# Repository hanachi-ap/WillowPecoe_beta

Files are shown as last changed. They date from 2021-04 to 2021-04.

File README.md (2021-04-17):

# WillowPecoe_beta

全国のWillowファンの皆様こんにちは。そしてβテストへようこそ。

## ビルドガイド(玄人向け)

MCUにProMicroを採用し、CherryMXスイッチ、PCB 3層サンドイッチと、ごくオーソドックスなスタイルを
採用しているので難しいところはないと思います。

基板がリバーシブルになっているので、パーツの取付面だけ注意ください。

## パーツリスト

- Pro Micro x1
- タクトスイッチ(2本足) x1
- MX用スイッチソケット x49
- ダイオード (TH or SMD) x50 
- フルカラーシリアルLED WS2812B x15 (opt)
- ロータリーエンコーダ x1  (opt)
  プッシュスイッチ対応。

  遊舎工房で販売している アメリカBourns社製 PEC12R-4222F-S0024 で動作を確認しています。
  その他秋月電子で販売しているロータリーエンコーダ（商品番号P-06357)もプシュスイッチ機能はありませんが動作確認済みです。

- 六角スペーサー(M2 7mm)  x13
- 六角スペーサー(M2 3.5mm) x6
- ネジ (M2 3mm) x38
- 2Uスタビライザ x1
- Cherry MX互換スイッチ x49
- キーキャップ (お好み)
  
## パーツの取付け
### 基板の表裏を決定
まず ロータリーエンコーダの位置を右か左か決めます。
 - 左側に置く場合、PCBのSide Aが表面になります。
 - 右側に置く場合、PCBのSide Bが表面になります。

### パーツのはんだ付け

#### ダイオード
- ダイオードは すべて裏面に取り付けます。 
  - SMD、TH どちらでも使えます。
  - 実際のところダイオードは表面につけても有効です。(見栄えの問題)
### スイッチソケット
- スイッチソケットはすべて裏面に取り付けます。

### RGB LED
- 表面側のパッドをジャンプさせます (Jump front sideと書いてあるところ)

- 表面に 3個、 裏面に12個取り付けます。
  - Side Aが表面の場合、 シルクのLED1からLED13に取り付けます。
  - Side Bが表面の場合、 シルクのLED16からLED30に取り付けます。

### ロータリーエンコーダ
- 表面からさして裏面をはんだ付けします。

### Pro Micro
 - ProMicroはコンスルーを使って表面に取り付けます。
 - ProMicroの実装面が内向きになるようにしてください。

### タクトスイッチ
  - 表面に取り付けます

## 組み立て

- トッププレートとPCBを3.5mmスペーサを使って取り付けます。
- スイッチを差し込みます。
- PCBと化粧板を7mmスペーサを使って取り付けます。
- トッププレートとボトムプレートを7mmスペーサを使って取り付けます。

## ファームウェア

- コンパイルしてください。ロリコンの位置によってキーマップが異なります。
  - Side A用: default
  - Side B用: side_b
  
## 既知の問題点

- アンダーグローの光がうまく廻りません。
  - アクリルプレートオプションを考慮します
  - 次の版では、簡単に表面の3つだけ優先的に光らせられるよう配線を見直します。
  - とりあえず表側の3個だけを光らすには 最初の5個だけを取り付けるか、ジャンパを這わせればOK。  

- PCBの表面に細かい油染みのような塗装ムラ?があります。
  - 製造委託先の品質に依存する問題かと思います。実質影響はありません。
  - 次の発注は別なところを考えてみます(量産のときはJLCPCBの価格は魅力なんだけど)
  
- ネジとスイッチが干渉する恐れがあるかも?
  - 作者手元のスイッチでは爪一枚入るくらいの余裕がありますが次の基板ではもう少し余裕持たせるようにします

- ファームウェアは開発途中です

- トッププレートのLEDを透過するスリットにはアクリルを埋め込む計画がありますが未実装です。
 
- 細かいキーレイアウトが作者の理想から少しだけ外れています。
  全体ををもう少し折り曲げたほうが好みなので修正が入るかもしれません

## 権利等
まだLICENSEを明記してませんが下記で公開する予定です。

- ファームウェア: GPL V2
- KiCAD設計データ: GPL V2
- KiCADフットプリント: MIT (thx foostan)
- 配列意匠: CC BY-SA 4.0 

以上です

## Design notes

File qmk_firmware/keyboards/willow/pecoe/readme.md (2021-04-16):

# pecoe

pecoe

*A short description of the keyboard/project*

* Keyboard Maintainer: [hanachi-ap](https://github.com/yourusername)
* Hardware Supported: *The PCBs, controllers supported*
* Hardware Availability: *Links to where you can find this hardware*

Make example for this keyboard (after setting up your build environment):

    make pecoe:default

Flashing example for this keyboard:

    make pecoe:default:flash

See the [build environment setup](https://docs.qmk.fm/#/getting_started_build_tools) and the [make instructions](https://docs.qmk.fm/#/getting_started_make_guide) for more information. Brand new to QMK? Start with our [Complete Newbs Guide](https://docs.qmk.fm/#/newbs).

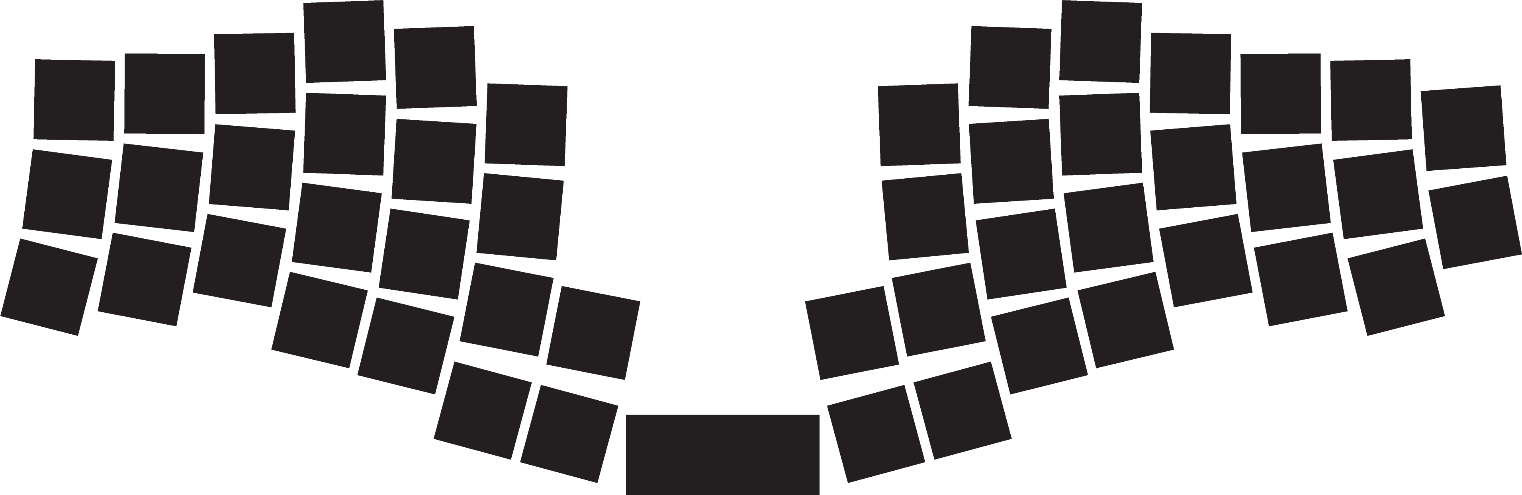
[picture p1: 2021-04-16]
pcb/kicad_lib/willow/png/F_switch_hole.png

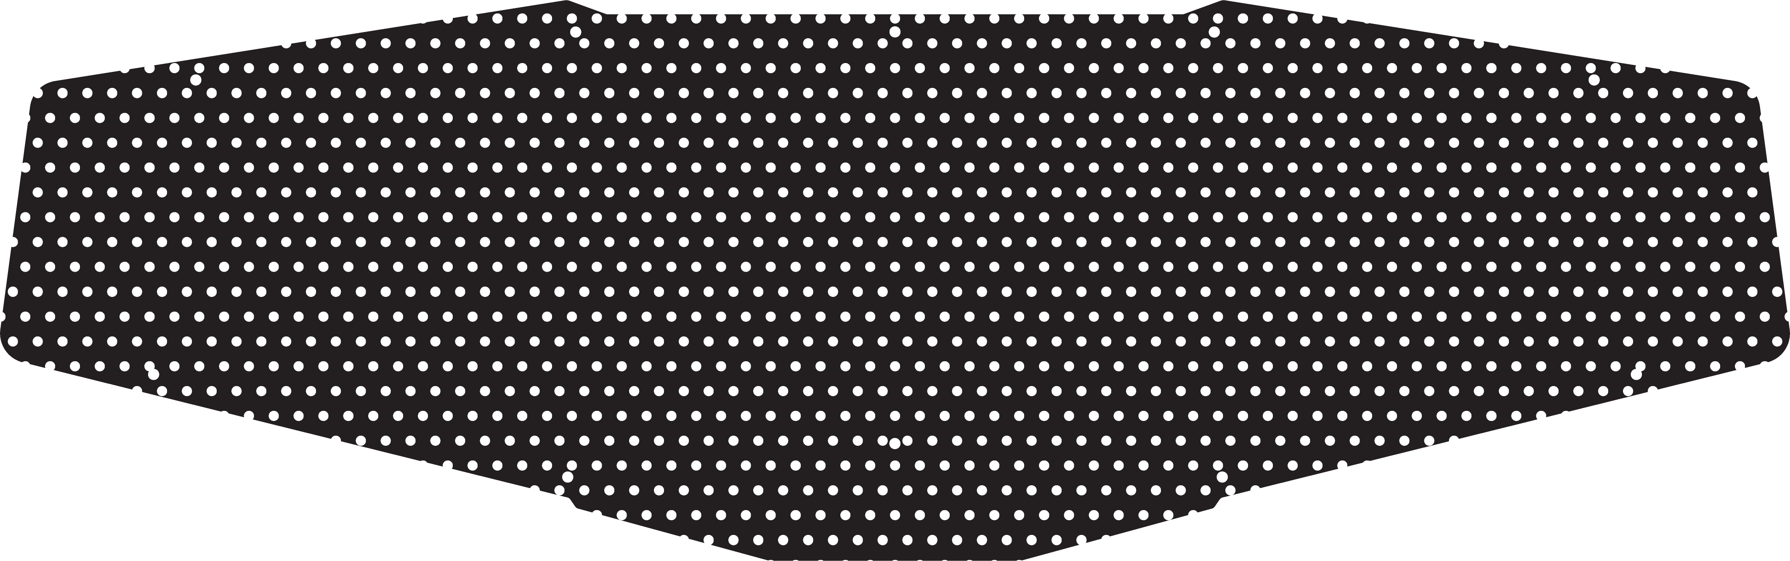
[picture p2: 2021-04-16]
pcb/WillowPecoe_bottom/bottom_pattern.png

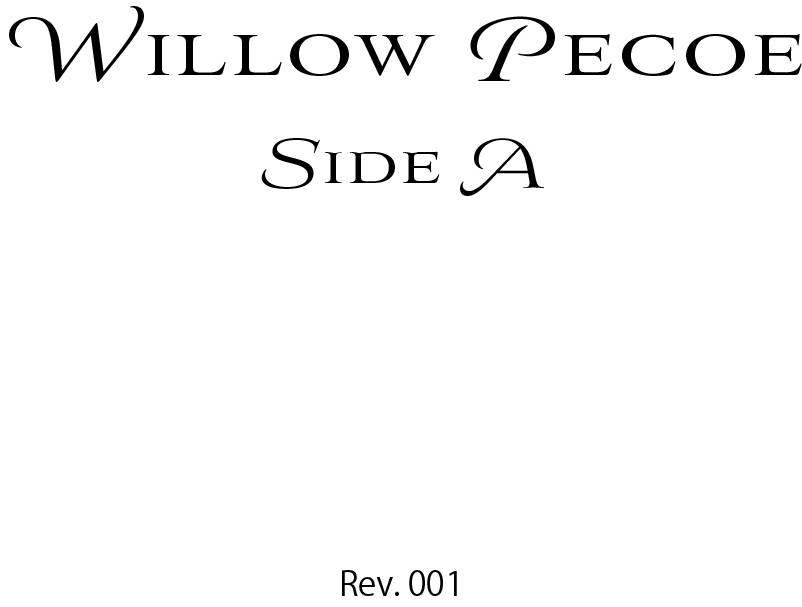
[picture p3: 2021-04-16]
pcb/WillowPecoe_pcb/Silk_F.png

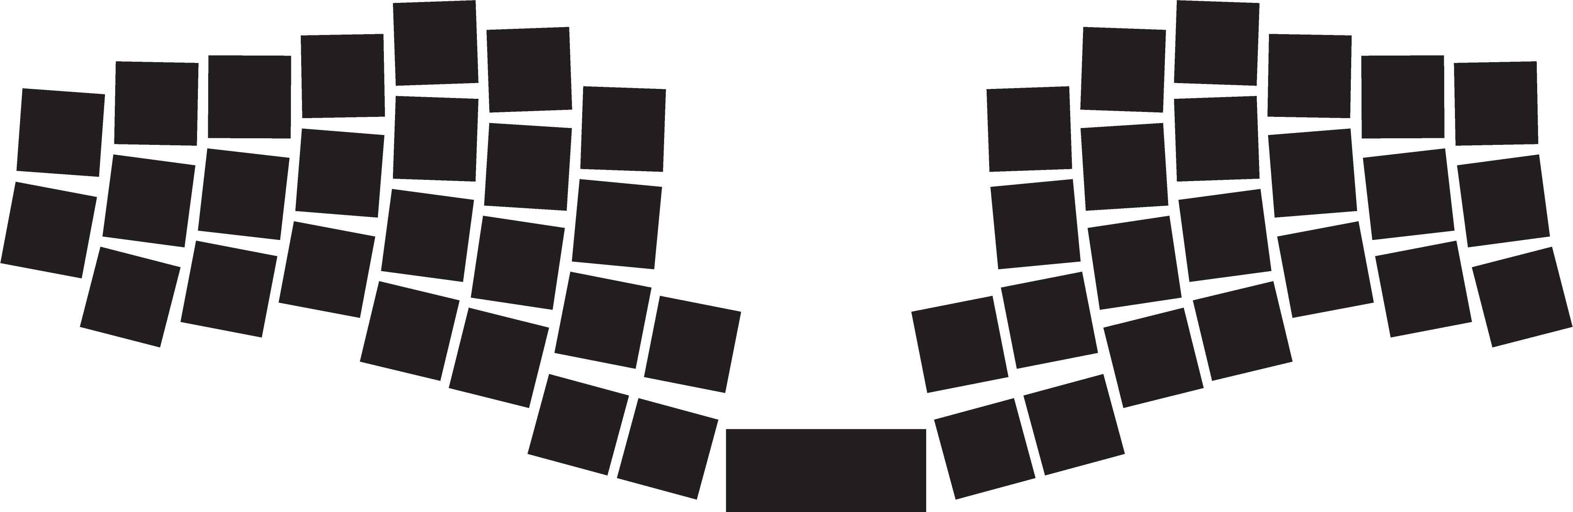
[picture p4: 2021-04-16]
pcb/kicad_lib/willow/png/B_switch_hole.png

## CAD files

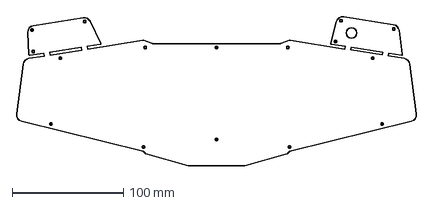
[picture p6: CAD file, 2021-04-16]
pcb/WillowPecoe_bottom/bottom_edge.dxf
360.8 x 134.4 mm

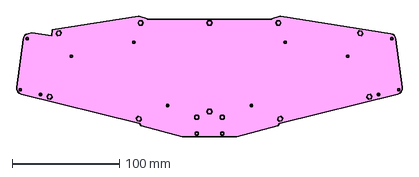
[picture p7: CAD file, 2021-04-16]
pcb/WillowPecoe_pcb/edge.dxf
360.8 x 112.8 mm

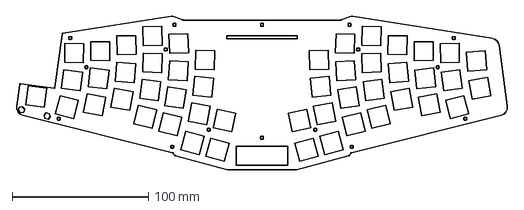
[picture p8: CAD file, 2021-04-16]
pcb/WillowPecoe_plate/edge_top.dxf
360.8 x 112.8 mm

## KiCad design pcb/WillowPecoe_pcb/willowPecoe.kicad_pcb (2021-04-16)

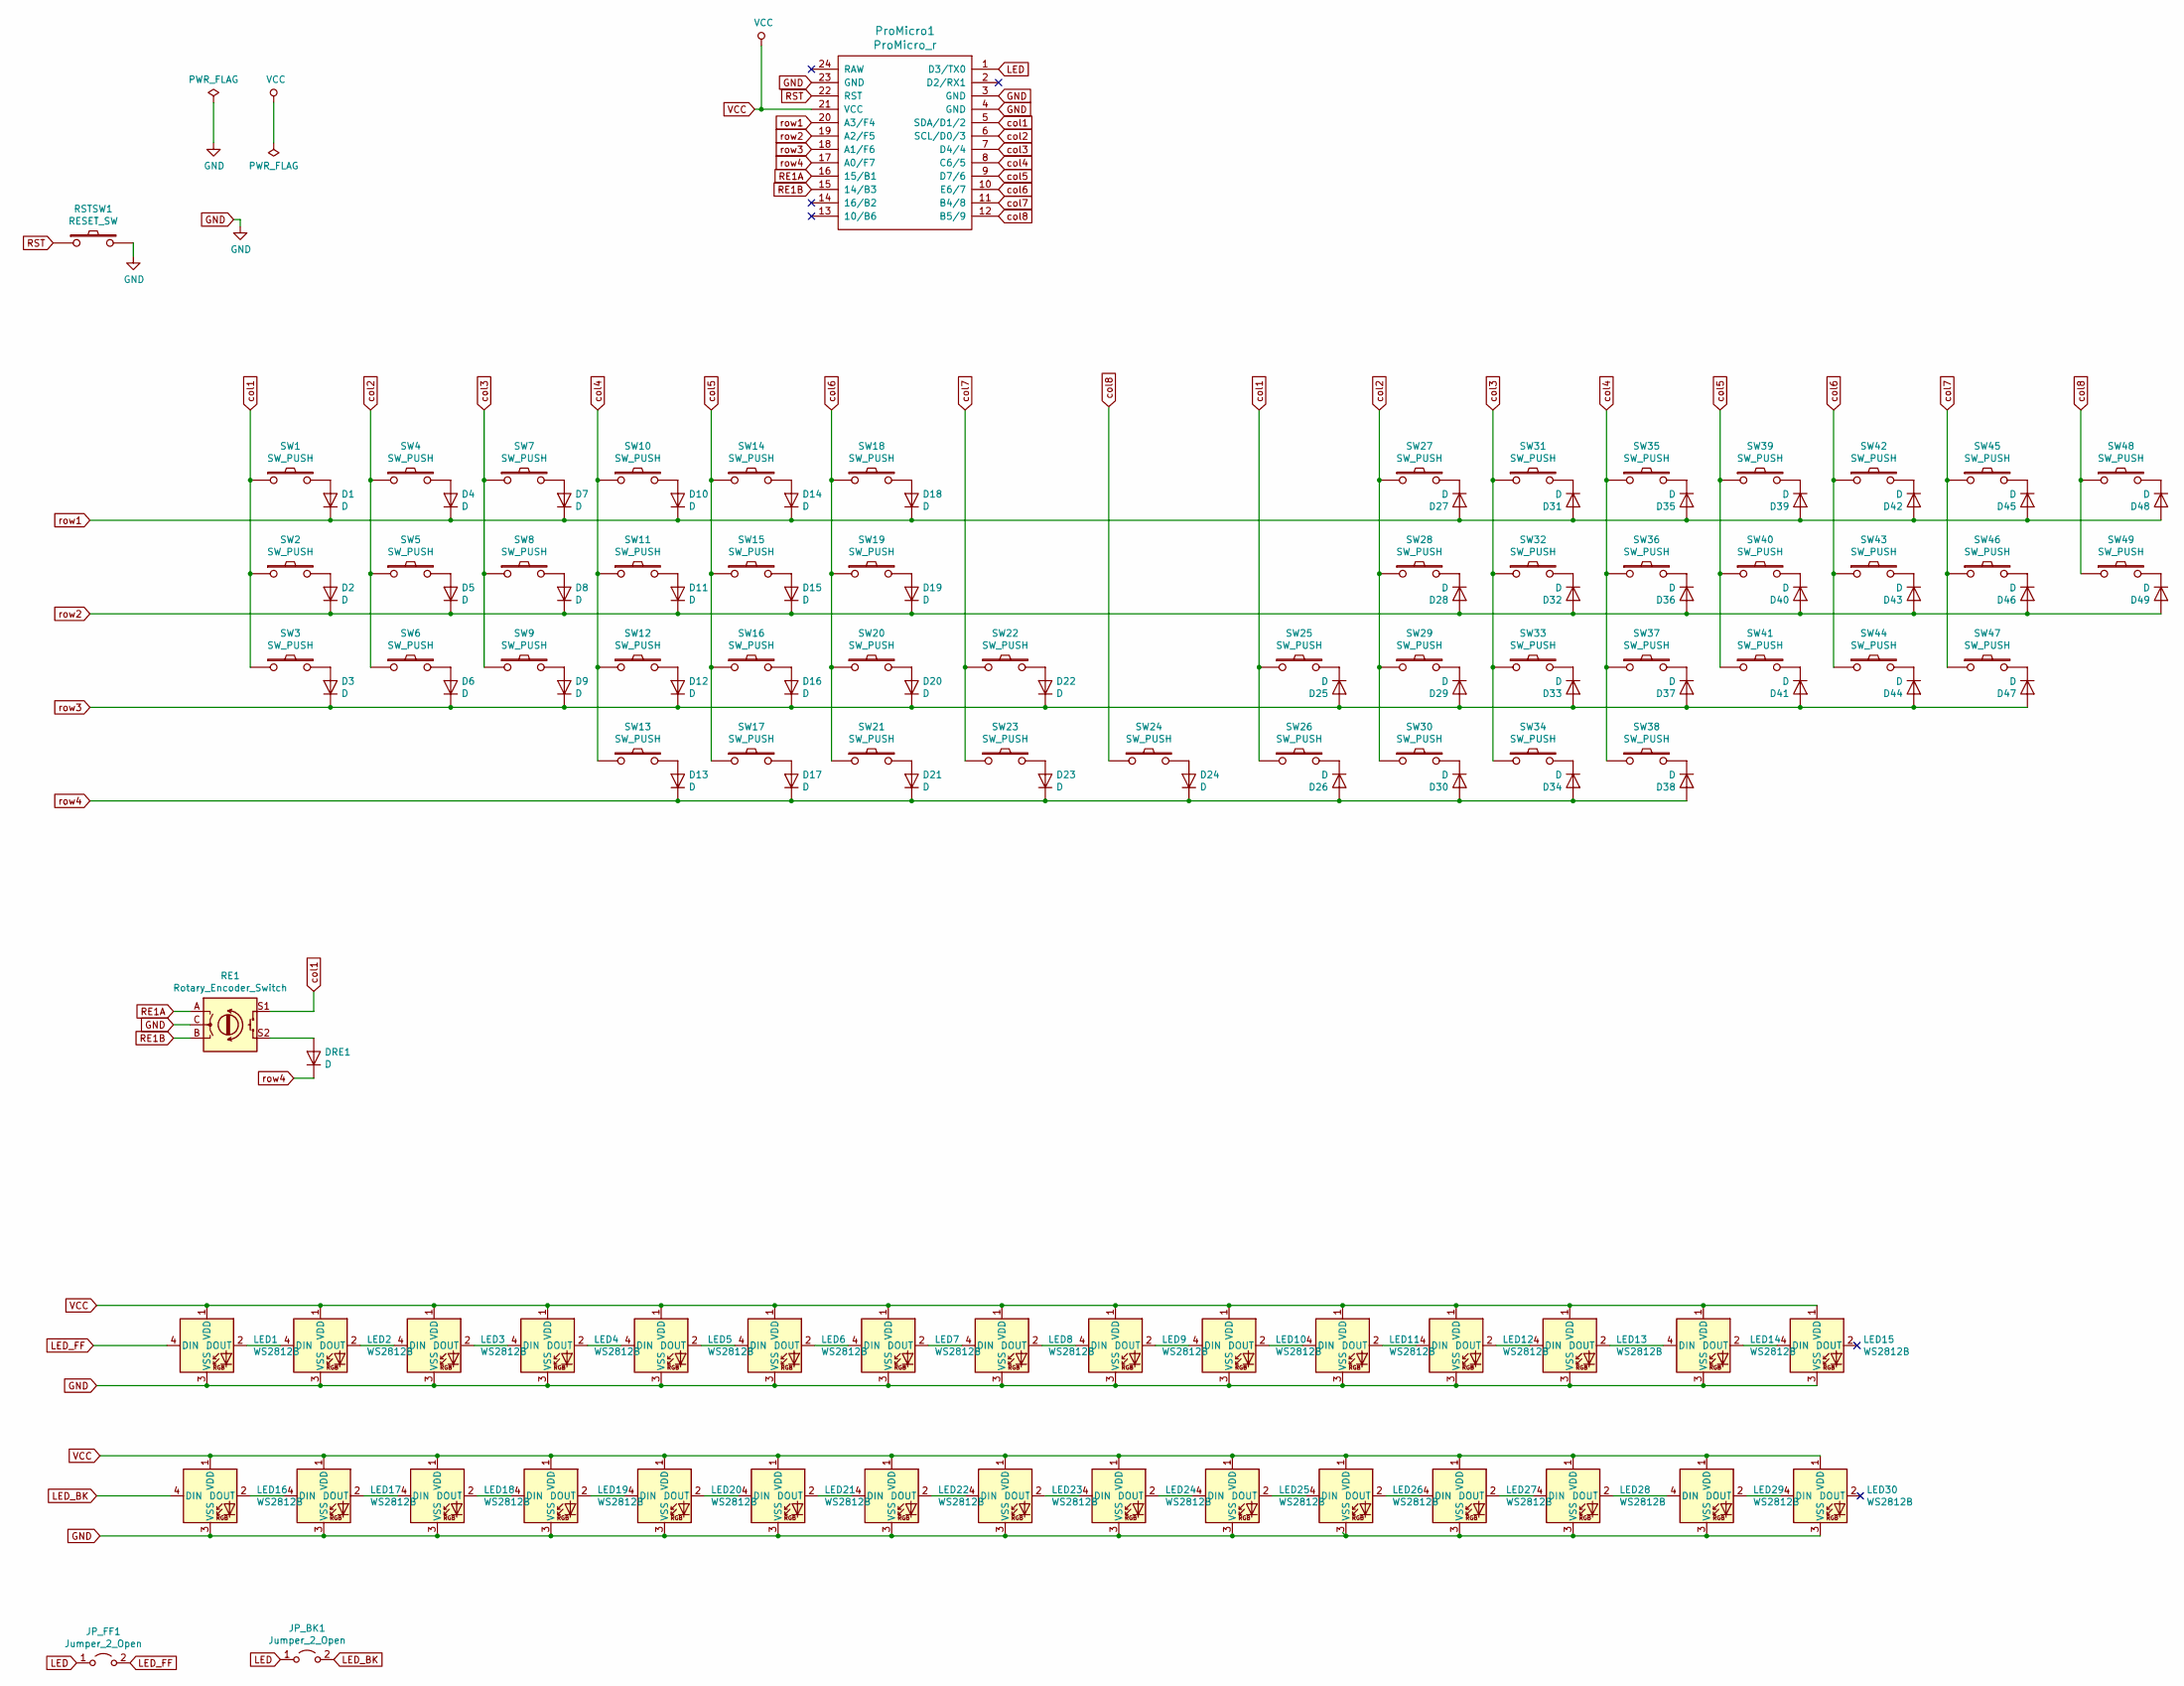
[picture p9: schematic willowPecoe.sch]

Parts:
D1, D2, D3, D4, D5, D6, D7, D8, D9, D10, D11, D12, D13, D14, D15, D16, D17, D18, D19, D20, D21, D22, D23, D24, D25, D26, D27, D28, D29, D30, D31, D32, D33, D34, D35, D36, D37, D38, D39, D40, D41, D42, D43, D44, D45, D46, D47, D48, D49: D; D3_TH_SMD
DRE1: D; D3_TH_SMD
JP_BK1: Jumper_2_Open; SolderJumper-2_P1.3mm_Open_RoundedPad1.0x1.5mm
JP_FF1: Jumper_2_Open; SolderJumper-2_P1.3mm_Open_RoundedPad1.0x1.5mm
LED1, LED2, LED3, LED4, LED5, LED6, LED7, LED8, LED9, LED10, LED11, LED12, LED13, LED14, LED15, LED16, LED17, LED18, LED19, LED20, LED21, LED22, LED23, LED24, LED25, LED26, LED27, LED28, LED29, LED30: WS2812B; LED_WS2812B_PLCC4_5.0x5.0mm_P3.2mm
ProMicro1: ProMicro_r; ProMicro_v2
RE1: Rotary_Encoder_Switch; RotaryEncoder_Alps_EC11E-Switch_Vertical_H20mm_rev2
RSTSW1: RESET_SW; ResetSW
SW1, SW2, SW3, SW4, SW5, SW6, SW7, SW8, SW9, SW10, SW11, SW12, SW13, SW14, SW15, SW16, SW17, SW18, SW19, SW20, SW21, SW22, SW23, SW24, SW25, SW26, SW27, SW28, SW29, SW30, SW31, SW32, SW33, SW34, SW35, SW36, SW37, SW38, SW39, SW40, SW41, SW42, SW43, SW44, SW45, SW46, SW47, SW48, SW49: SW_PUSH; CherryMX_MidHeight_Hotswap

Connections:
GND: LED1.3 (VSS), LED2.3 (VSS), LED3.3 (VSS), LED4.3 (VSS), LED5.3 (VSS), LED6.3 (VSS), LED7.3 (VSS), LED8.3 (VSS), LED9.3 (VSS), LED10.3 (VSS), LED11.3 (VSS), LED12.3 (VSS), LED13.3 (VSS), LED14.3 (VSS), LED15.3 (VSS), LED16.3 (VSS), LED17.3 (VSS), LED18.3 (VSS), LED19.3 (VSS), LED20.3 (VSS), LED21.3 (VSS), LED22.3 (VSS), LED23.3 (VSS), LED24.3 (VSS), LED25.3 (VSS), LED26.3 (VSS), LED27.3 (VSS), LED28.3 (VSS), LED29.3 (VSS), LED30.3 (VSS), ProMicro1.3 (GND), ProMicro1.4 (GND), ProMicro1.23 (GND), RE1.C, RSTSW1.2
LED: JP_BK1.1 (A), JP_FF1.1 (A), ProMicro1.1 (D3/TX0); also elsewhere on the board
LED_BK: JP_BK1.2 (B), LED16.4 (DIN); also elsewhere on the board
LED_FF: JP_FF1.2 (B), LED1.4 (DIN); also elsewhere on the board
unnamed: D1.2 (A), SW1.2
unnamed: D2.2 (A), SW2.2
unnamed: D3.2 (A), SW3.2
unnamed: D4.2 (A), SW4.2
unnamed: D5.2 (A), SW5.2
unnamed: D6.2 (A), SW6.2
unnamed: D7.2 (A), SW7.2
unnamed: D8.2 (A), SW8.2
unnamed: D9.2 (A), SW9.2
unnamed: D10.2 (A), SW10.2
unnamed: D11.2 (A), SW11.2
unnamed: D12.2 (A), SW12.2
unnamed: D13.2 (A), SW13.2
unnamed: D14.2 (A), SW14.2
unnamed: D15.2 (A), SW15.2
unnamed: D16.2 (A), SW16.2
unnamed: D17.2 (A), SW17.2
unnamed: D18.2 (A), SW18.2
unnamed: D19.2 (A), SW19.2
unnamed: D20.2 (A), SW20.2
unnamed: D21.2 (A), SW21.2
unnamed: D22.2 (A), SW22.2
unnamed: D23.2 (A), SW23.2
unnamed: D24.2 (A), SW24.2
unnamed: D25.1 (K), SW25.2
unnamed: D26.1 (K), SW26.2
unnamed: D27.1 (K), SW27.2
unnamed: D28.1 (K), SW28.2
unnamed: D29.1 (K), SW29.2
unnamed: D30.1 (K), SW30.2
unnamed: D31.1 (K), SW31.2
unnamed: D32.1 (K), SW32.2
unnamed: D33.1 (K), SW33.2
unnamed: D34.1 (K), SW34.2
unnamed: D35.1 (K), SW35.2
unnamed: D36.1 (K), SW36.2
unnamed: D37.1 (K), SW37.2
unnamed: D38.1 (K), SW38.2
unnamed: D39.1 (K), SW39.2
unnamed: D40.1 (K), SW40.2
unnamed: D41.1 (K), SW41.2
unnamed: D42.1 (K), SW42.2
unnamed: D43.1 (K), SW43.2
unnamed: D44.1 (K), SW44.2
unnamed: D45.1 (K), SW45.2
unnamed: D46.1 (K), SW46.2
unnamed: D47.1 (K), SW47.2
unnamed: D48.1 (K), SW48.2
unnamed: D49.1 (K), SW49.2
unnamed: DRE1.2 (A), RE1.S2
unnamed: LED1.2 (DOUT), LED2.4 (DIN)
unnamed: LED2.2 (DOUT), LED3.4 (DIN)
unnamed: LED3.2 (DOUT), LED4.4 (DIN)
unnamed: LED4.2 (DOUT), LED5.4 (DIN)
unnamed: LED5.2 (DOUT), LED6.4 (DIN)
unnamed: LED6.2 (DOUT), LED7.4 (DIN)
unnamed: LED7.2 (DOUT), LED8.4 (DIN)
unnamed: LED8.2 (DOUT), LED9.4 (DIN)
unnamed: LED10.2 (DOUT), LED11.4 (DIN)
unnamed: LED9.2 (DOUT), LED10.4 (DIN)
unnamed: LED11.2 (DOUT), LED12.4 (DIN)
unnamed: LED12.2 (DOUT), LED13.4 (DIN)
unnamed: LED13.2 (DOUT), LED14.4 (DIN)
unnamed: LED14.2 (DOUT), LED15.4 (DIN)
unnamed: LED16.2 (DOUT), LED17.4 (DIN)
unnamed: LED17.2 (DOUT), LED18.4 (DIN)
unnamed: LED18.2 (DOUT), LED19.4 (DIN)
unnamed: LED19.2 (DOUT), LED20.4 (DIN)
unnamed: LED20.2 (DOUT), LED21.4 (DIN)
unnamed: LED21.2 (DOUT), LED22.4 (DIN)
unnamed: LED22.2 (DOUT), LED23.4 (DIN)
unnamed: LED23.2 (DOUT), LED24.4 (DIN)
unnamed: LED24.2 (DOUT), LED25.4 (DIN)
unnamed: LED25.2 (DOUT), LED26.4 (DIN)
unnamed: LED26.2 (DOUT), LED27.4 (DIN)
unnamed: LED27.2 (DOUT), LED28.4 (DIN)
unnamed: LED28.2 (DOUT), LED29.4 (DIN)
unnamed: LED29.2 (DOUT), LED30.4 (DIN)
RE1A: ProMicro1.16 (15/B1), RE1.A
RE1B: ProMicro1.15 (14/B3), RE1.B
RST: ProMicro1.22 (RST), RSTSW1.1
VCC: LED1.1 (VDD), LED2.1 (VDD), LED3.1 (VDD), LED4.1 (VDD), LED5.1 (VDD), LED6.1 (VDD), LED7.1 (VDD), LED8.1 (VDD), LED9.1 (VDD), LED10.1 (VDD), LED11.1 (VDD), LED12.1 (VDD), LED13.1 (VDD), LED14.1 (VDD), LED15.1 (VDD), LED16.1 (VDD), LED17.1 (VDD), LED18.1 (VDD), LED19.1 (VDD), LED20.1 (VDD), LED21.1 (VDD), LED22.1 (VDD), LED23.1 (VDD), LED24.1 (VDD), LED25.1 (VDD), LED26.1 (VDD), LED27.1 (VDD), LED28.1 (VDD), LED29.1 (VDD), LED30.1 (VDD), ProMicro1.21 (VCC)
col1: ProMicro1.5 (SDA/D1/2), RE1.S1, SW1.1, SW2.1, SW3.1, SW25.1, SW26.1
col2: ProMicro1.6 (SCL/D0/3), SW4.1, SW5.1, SW6.1, SW27.1, SW28.1, SW29.1, SW30.1
col3: ProMicro1.7 (D4/4), SW7.1, SW8.1, SW9.1, SW31.1, SW32.1, SW33.1, SW34.1
col4: ProMicro1.8 (C6/5), SW10.1, SW11.1, SW12.1, SW13.1, SW35.1, SW36.1, SW37.1, SW38.1
col5: ProMicro1.9 (D7/6), SW14.1, SW15.1, SW16.1, SW17.1, SW39.1, SW40.1, SW41.1
col6: ProMicro1.10 (E6/7), SW18.1, SW19.1, SW20.1, SW21.1, SW42.1, SW43.1, SW44.1
col7: ProMicro1.11 (B4/8), SW22.1, SW23.1, SW45.1, SW46.1, SW47.1
col8: ProMicro1.12 (B5/9), SW24.1, SW48.1, SW49.1
row1: D1.1 (K), D4.1 (K), D7.1 (K), D10.1 (K), D14.1 (K), D18.1 (K), D27.2 (A), D31.2 (A), D35.2 (A), D39.2 (A), D42.2 (A), D45.2 (A), D48.2 (A), ProMicro1.20 (A3/F4)
row2: D2.1 (K), D5.1 (K), D8.1 (K), D11.1 (K), D15.1 (K), D19.1 (K), D28.2 (A), D32.2 (A), D36.2 (A), D40.2 (A), D43.2 (A), D46.2 (A), D49.2 (A), ProMicro1.19 (A2/F5)
row3: D3.1 (K), D6.1 (K), D9.1 (K), D12.1 (K), D16.1 (K), D20.1 (K), D22.1 (K), D25.2 (A), D29.2 (A), D33.2 (A), D37.2 (A), D41.2 (A), D44.2 (A), D47.2 (A), ProMicro1.18 (A1/F6)
row4: D13.1 (K), D17.1 (K), D21.1 (K), D23.1 (K), D24.1 (K), D26.2 (A), D30.2 (A), D34.2 (A), D38.2 (A), DRE1.1 (K), ProMicro1.17 (A0/F7)

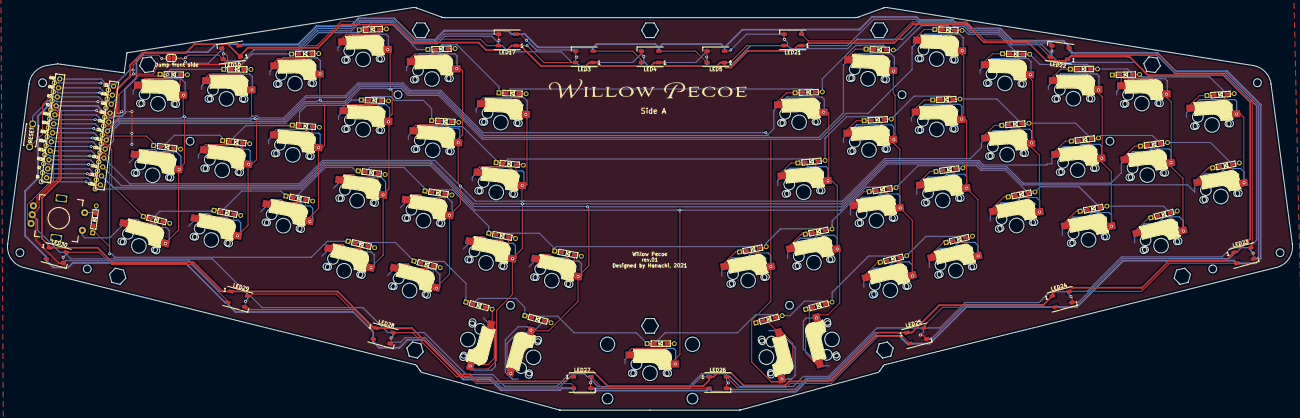
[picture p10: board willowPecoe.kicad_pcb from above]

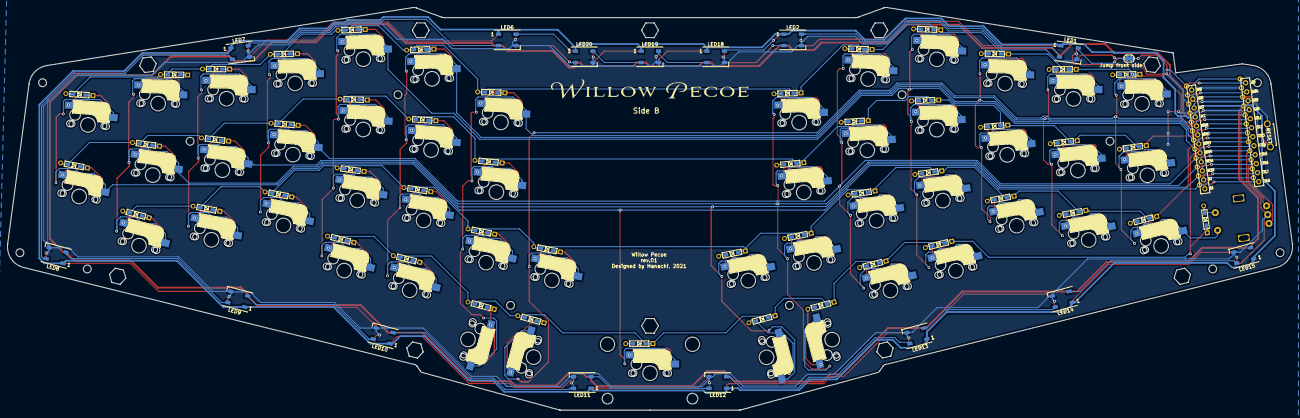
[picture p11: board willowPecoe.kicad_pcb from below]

Board: 2 copper layers, 360.1 x 112.8 mm, 134 parts (16 on the bottom side), 98 nets.

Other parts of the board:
Jump front side: Jumper_2_Open; SolderJumper-2_P1.3mm_Open_RoundedPad1.0x1.5mm
Jump front side#2: Jumper_2_Open; SolderJumper-2_P1.3mm_Open_RoundedPad1.0x1.5mm

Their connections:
LED: Jump front side.1, Jump front side#2.1; also elsewhere on the board
LED_BK: Jump front side.2; also elsewhere on the board
LED_FF: Jump front side#2.2; also elsewhere on the board

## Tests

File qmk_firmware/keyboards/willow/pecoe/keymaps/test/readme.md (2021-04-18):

# The test keymap for willow/pecoe

This test firmware is only for left-sided rotary encoder (Side-A is surface)
for now.

It starts RGB light with test pattern.  Test pattern means all LEDs will light
and change those color: red, green, blue at constant interval.

Test keymap is very simple to test keys.  No layersk, no tappings or so.  You
can test all keys (and a rotary encoder also) with
<https://config.qmk.fm/#/test/> easily.

## Rotary Encoder

Rotation of a rotary encoder is parsed as `Page Up` (counter clockwise) or
`Page Down` (clockwise) keys as normal.

Pressing switch of rotary encoder changes hidden-internal mode to parse
rotation of rotary encoder.  When changed the mode, rotation is parsed as
`Home` (counter clockwise) or `End` (clockwise).  Then press a switch again to
return to the original parsing mode.

Parsing mode is indicated with RGB LEDs.  For normal mode, RGB light will be
enabled with test pattern.  For alternative mode, RGB light will be disabeld,
all LEDs are turned off.

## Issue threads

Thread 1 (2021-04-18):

βビルドレポート兼ビルドログ

koron, 2021-04-18:
ビルドレポート兼ビルドログをお届けします。
何かの参考になれば幸いです。

---

油シミ(?) はソルダーレジストの塗りムラっぽい。
ベンジンや無水エタノールでは解消しなかった。

ムラは片側=表側(F)に集中しているみたい。
特にボトムプレートをみるとわかるのだけど、
ドット(水玉)の入っている裏側(B)には驚くほどムラがない。
なので外から見える場所には裏側(B)を使うのがよさそう。

関連つぶやきハッシュタグ
[`#自作キーボード #WillowPecoe #βテスト`](<https://twitter.com/search?q=%23WillowPecoe>)

ボトムの切り取り線、メッキはないほうが良さそう。でてくるゴミ的に。
切り取り部はもう少し長い=基板間の隙間が多いほうが折りやすそう。
今は切り込みを入れた後に折り取るのに幅広のペンチが要る。
長ければ指でいけそう。

Side-BでProMicroとスペーサーが干渉することがある。
普通の六角スペーサーの場合、
ProMicroを取り付けてからスペーサーを取り付けたほうが良い。
もしくは細身の六角スペーサー(kochi keyboardさん取り扱い)を使うか。
PCB確認したが0.20~0.25mmずらして、
直径約4.3mm確保すると六角スペーサーもスムーズに付けられそう。

カバープレートのスペーサーは6.0mmを選択。
プッシュスイッチ付きロータリエンコーダを使うことを考えると
ココは低ければ低いほど良いはず。
が、ツマミ次第なところもある。
できれば5.0mmに換装したい。
キットとして7.0mmを選択するのはとても理解できる。

懸念していた一部ネジ穴とキースイッチとの干渉はギリ大丈夫そう。
超低頭ネジでギリギリ、ナベネジだと結構余裕があった。

ロータリーエンコーダ:
遊舎工房が売り切れだったので、ルツで [EVE-VCGJL016B](https://www.marutsu.co.jp/pc/i/65443/) を購入。
そのほかに秋月電子でプッシュボタンがないものの2種類:
[EC12E2420801](https://akizukidenshi.com/catalog/g/gP-06357/),
[EC12E2420803](https://akizukidenshi.com/catalog/g/gP-06358/)
購入。

EVE-VCGJL016B + 5.0mm スペーサーで良さそう。
EC12E2420803 は回転が重い。
EC12はエンコーダーのハウジング上部に突起があり6.0mmスペーサーでも浮く。
7.0mmなら大丈夫。
EVE-VCGJL016B + 5.0mmスペーサーで行くことにした。

ロータリーエンコーダーの取り付け方向は左側を選択。

基板側面はガンダムマーカーガンダムブラックで塗った。
マッキー同様にアルコールやフラックスクリーナーには弱いが、
マッキーよりも乾燥が速くまた指移りもしない。

手持ちのロータリーエンコーダのノブの直径が25mmだった。
これだと隣のキースイッチと干渉してしまうかも? 失敗したかも。
フットプリント中心間が23.75mm
PCBレイアウトで確認:
ロータリーエンコーダの軸中心から
キースイッチのフットプリント外側まで約14mmはあるから
25mm(半径12.5mm)なら1.5mmのクリアランスがあるはず。
なので使えそう

[組み立て作業ライブのアーカイブ](https://www.youtube.com/watch?v=VlxoZLRWPAs)

LEDのGNDが異様にハンダ付けしにくい。
広大なベタGNDに熱が逃げるのでLEDのハンダ付けに推奨される220~250℃や
若干高めの270℃では温度不足からのハンダ付け不良を極めて起こしやすい。
320℃まで上げれば比較的安定して付くのだが
LEDを熱で破壊する確率が上がるので初心者から中級者にはきつそう。

カバープレートのスペーサー5.0mmはPro Microのコンスルーの足と干渉した。
よって6.0mmに変更。
キットとしては安定のためにも7.0mmがベターだろう。

ボトムプレートは水玉模様が下になるほうを選択。

傾斜を付けるためのゴム足は6個あると安定した。
[この写真](https://twitter.com/kaoriya/status/1383494245001043970/photo/2)は
上からタカチのTB-16(約8.0mm)、
和気産業のCN-002(高さ3.8mm)、
タカチのTB-8(高さ2.6mm)となっている。

表側のLED(03, 04, 05)のメンテナンス性が著しく悪い。
ハンダ付けの修正や部品交換するにはトッププレートを外す必要があり大変そう。
Willow64のようにB側からのほうがそのあたりがいじりやすくなる。

テスト用のファーム(キーマップ)を作製した。
これはのちにPR予定。
以下はそのテスト用ファームで確認した問題。

まだ切り分けが済んでいないが
使用したロータリーエンコーダ EVE-VCGJL016B 周りで以下の不具合が見つかってる。

*   回転が取得できていない

    `encoder_update_user()` が呼ばれているかも未検証。

*   プッシュスイッチは機能するが問題が発生している

    ロータリーエンコーダーの回転位置によってはキー入力のゴーストが発生する。
    ある位置で問題なくプッシュスイッチが機能する(`SW_ENCODER`が発火する)時に、
    1クリック分回転させてから再度プッシュスイッチを押すと
    `SW_ENCODER`は発火するが同時に右隣の3つのキー(ESC+Tab+LSHIFT)の同時押しも発火する。

    回路のような気もするが、ダイオードの取り付けミスの可能性、
    ロータリーエンコーダの違いのせいという可能性も否定できない。

    詳細は未検証。

koron, 2021-04-18:
> プッシュスイッチは機能するが問題が発生している

> ロータリーエンコーダの違いのせい

ほぼコレで確定。
[EVE-VCGJL016Bのデータシート](https://www.marutsu.co.jp/contents/shop/marutsu/datasheet/atc0000cj15.pdf) を見ると
3ピンの中心が B になってる。一方回路図やALPSのはGNDになってる。

あとで修正ジャンパやカットで確かめてみる。

koron, 2021-04-18:
中心ピンをカットしてGNDをMP(ケース)のほうに接続した。

これでゴースト入力はなくなった。
しかし回転は取れてない。
まぁこれはencoderのドライバの設定で何とかしたほうがよさそう。

hanachi-ap, 2021-04-18:
データシートではチャタリング除去のためのフィルター回路が推奨されていますが、このプロダクトでは省いています(ファームの方でなんとかする)
回転自体が取れないのとは直接の関係はなさそうですが。

koron, 2021-04-18:
いろいろありがとうございます。
とりあえずエンコーダーの件は忘れてください。

キットに同梱するつもりなら関係ないですし、
そうでない場合も「EVE-VCGJL016Bは使えません」とか
「これこれの製品を使ってください」が書いてあれば済むはずですので。

koron, 2021-04-18:
あ、1つ追加で報告なんですが、
トッププレートのロータリーエンコーダ用の穴をもう少し大きくしてもらえると、
トッププレートを外さずにロータリーエンコーダーを交換できメンテ性があがります。

koron, 2021-04-19:
一応追加報告です

> 回路のような気もするが、ダイオードの取り付けミスの可能性、
> ロータリーエンコーダの違いのせいという可能性も否定できない。

これは完全にロータリーエンコーダの違いのせいでした。

https://industrial.panasonic.com/cdbs/www-data/pdf/ATT0000/ATT0000C5.pdf より回路図を引用

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

プッシュスイッチとエンコーダがGNDとしてCOMMを共用しているのが原因です。

> 1クリック分回転させてから再度プッシュスイッチを押すと
> SW_ENCODERは発火するが同時に右隣の3つのキー(ESC+Tab+LSHIFT)の同時押しも発火する

報告したこの現象も、この回路図であれば納得です。

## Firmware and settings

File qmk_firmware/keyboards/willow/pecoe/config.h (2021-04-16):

/*
Copyright 2021 hanachi-ap

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
You should have received a copy of the GNU General Public License
along with this program.  If not, see <http://www.gnu.org/licenses/>.
*/

#pragma once

#include "config_common.h"

/* USB Device descriptor parameter */
#define VENDOR_ID 0xBB01
#define PRODUCT_ID 0x0010
#define DEVICE_VER 0x0001
#define MANUFACTURER Hanachi
#define PRODUCT WillowPecoe

/* key matrix size */
#define MATRIX_ROWS 4
#define MATRIX_COLS 16

/*
 * Keyboard Matrix Assignments
 *
 * Change this to how you wired your keyboard
 * COLS: AVR pins used for columns, left to right
 * ROWS: AVR pins used for rows, top to bottom
 * DIODE_DIRECTION: COL2ROW = COL = Anode (+), ROW = Cathode (-, marked on diode)
 *                  ROW2COL = ROW = Anode (+), COL = Cathode (-, marked on diode)
 *
 */
#define MATRIX_ROW_PINS { F4, F5, F6, F7}
#define MATRIX_COL_PINS { D1, D0, D4, C6, D7, E6, B4, B5, D1, D0, D4, C6, D7, E6, B4, B5}
#define UNUSED_PINS
/* COL2ROW, ROW2COL */
#define DIODE_DIRECTION COL2ROW

/*
 * Split Keyboard specific options, make sure you have 'SPLIT_KEYBOARD = yes' in your rules.mk, and define SOFT_SERIAL_PIN.
 */
//#define SOFT_SERIAL_PIN D0  // or D1, D2, D3, E6

//#define LED_NUM_LOCK_PIN B0
//#define LED_CAPS_LOCK_PIN B1
//#define LED_SCROLL_LOCK_PIN B2
//#define LED_COMPOSE_PIN B3
//#define LED_KANA_PIN B4

//#define BACKLIGHT_PIN B7
//#define BACKLIGHT_LEVELS 3
//#define BACKLIGHT_BREATHING

#define RGB_DI_PIN D3
#ifdef RGB_DI_PIN
#    define RGBLED_NUM 15
#    define RGBLIGHT_HUE_STEP 8
#    define RGBLIGHT_SAT_STEP 8
#    define RGBLIGHT_VAL_STEP 8
#    define RGBLIGHT_LIMIT_VAL 255 /* The maximum brightness level */
#    define RGBLIGHT_SLEEP  /* If defined, the RGB lighting will be switched off when the host goes to sleep */
/*== all animations enable ==*/
#    define RGBLIGHT_ANIMATIONS
/*== or choose animations ==*/
//#    define RGBLIGHT_EFFECT_BREATHING
//#    define RGBLIGHT_EFFECT_RAINBOW_MOOD
//#    define RGBLIGHT_EFFECT_RAINBOW_SWIRL
//#    define RGBLIGHT_EFFECT_SNAKE
//#    define RGBLIGHT_EFFECT_KNIGHT
//#    define RGBLIGHT_EFFECT_CHRISTMAS
//#    define RGBLIGHT_EFFECT_STATIC_GRADIENT
//#    define RGBLIGHT_EFFECT_RGB_TEST
//#    define RGBLIGHT_EFFECT_ALTERNATING
/*== customize breathing effect ==*/
/*==== (DEFAULT) use fixed table instead of exp() and sin() ====*/
//#    define RGBLIGHT_BREATHE_TABLE_SIZE 256      // 256(default) or 128 or 64
/*==== use exp() and sin() ====*/
//#    define RGBLIGHT_EFFECT_BREATHE_CENTER 1.85  // 1 to 2.7
//#    define RGBLIGHT_EFFECT_BREATHE_MAX    255   // 0 to 255
#endif

/* Debounce reduces chatter (unintended double-presses) - set 0 if debouncing is not needed */
#define DEBOUNCE 5

/* define if matrix has ghost (lacks anti-ghosting diodes) */
//#define MATRIX_HAS_GHOST

/* Mechanical locking support. Use KC_LCAP, KC_LNUM or KC_LSCR instead in keymap */
#define LOCKING_SUPPORT_ENABLE
/* Locking resynchronize hack */
#define LOCKING_RESYNC_ENABLE

/* If defined, GRAVE_ESC will always act as ESC when CTRL is held.
 * This is useful for the Windows task manager shortcut (ctrl+shift+esc).
 */
//#define GRAVE_ESC_CTRL_OVERRIDE

/*
 * Force NKRO
 *
 * Force NKRO (nKey Rollover) to be enabled by default, regardless of the saved
 * state in the bootmagic EEPROM settings. (Note that NKRO must be enabled in the
 * makefile for this to work.)
 *
 * If forced on, NKRO can be disabled via magic key (default = LShift+RShift+N)
 * until the next keyboard reset.
 *
 * NKRO may prevent your keystrokes from being detected in the BIOS, but it is
 * fully operational during normal computer usage.
 *
 * For a less heavy-handed approach, enable NKRO via magic key (LShift+RShift+N)
 * or via bootmagic (hold SPACE+N while plugging in the keyboard). Once set by
 * bootmagic, NKRO mode will always be enabled until it is toggled again during a
 * power-up.
 *
 */
//#define FORCE_NKRO

/*
 * Feature disable options
 *  These options are also useful to firmware size reduction.
 */

/* disable debug print */
//#define NO_DEBUG

/* disable print */
//#define NO_PRINT

/* disable action features */
//#define NO_ACTION_LAYER
//#define NO_ACTION_TAPPING
//#define NO_ACTION_ONESHOT

/* disable these deprecated features by default */
#define NO_ACTION_MACRO
#define NO_ACTION_FUNCTION

/* Bootmagic Lite key configuration */
//#define BOOTMAGIC_LITE_ROW 0
//#define BOOTMAGIC_LITE_COLUMN 0


#define ENCODERS_PAD_A { B3}
#define ENCODERS_PAD_B { B1}
#define ENCODER_RESOLUTIONS { 4 }

#define AUTO_SHIFT_TIMEOUT 210
#define TAPPING_TERM 200
#define PERMISSIVE_HOLD
//#define RETRO_TAPPING
//#define TAPPING_FORCE_HOLD
//#define IGNORE_MOD_TAP_INTERRUPT
//#define AUTO_SHIFT_REPEAT

#define RGBLIGHT_LAYERS
#define RGBLIGHT_MAX_LAYERS 8

#define DYNAMIC_KEYMAP_LAYER_COUNT 5

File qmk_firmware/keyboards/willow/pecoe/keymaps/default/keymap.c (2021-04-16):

/* Copyright 2021 hanachi-ap
 *
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
 * You should have received a copy of the GNU General Public License
 * along with this program.  If not, see <http://www.gnu.org/licenses/>.
 */
#include QMK_KEYBOARD_H

// Defines names for use in layer keycodes and the keymap
enum layer_names {
    _QWERTY,
    _NUM,
    _FN,
    _SYS,
    _EXT,
};

// Defines the keycodes used by our macros in process_record_user
enum custom_keycodes {
    SW_ENCODER = SAFE_RANGE
};

const uint16_t PROGMEM keymaps[][MATRIX_ROWS][MATRIX_COLS] = {
[_QWERTY]=LAYOUT(   //QWERTY
			KC_ESC	,	KC_Q	,	KC_W	,	KC_E	,	KC_R	,	KC_T	,							KC_Y	,	KC_U	,	KC_I	,	KC_O	,	KC_P	,	KC_LBRC	,	KC_RBRC	,
			KC_TAB	,	KC_A	,	KC_S	,	KC_D	,	KC_F	,	KC_G	,							KC_H	,	KC_J	,	KC_K	,	KC_L	,	KC_SCLN	,	KC_MINS	,	KC_ENT	,
			KC_LSFT	,	KC_Z	,	KC_X	,	KC_C	,	KC_V	,	KC_B	,	KC_DEL	,			KC_LGUI	,	KC_N	,	KC_M	,	KC_COMM	,	KC_DOT	,	KC_SLSH	,	KC_RSFT	,
	SW_ENCODER	,							WIN_T(KC_LEFT)	,	ALT_T(KC_RIGHT)	,	LT(_NUM,KC_SPC)	,	CTL_T(KC_F13)	,	LT(_NUM, KC_F13)	,	SFT_T(KC_ENT)	,	LT(_FN, KC_BSPC)	,	LT(_NUM, KC_DOWN)	,	LT(_SYS, KC_UP)
),

[_NUM]=LAYOUT(    // NUM (Num pad)
			KC_GRV	,	KC_1	,	KC_2	,	KC_3	,	KC_4	,	KC_5	,							KC_6	,	KC_7	,	KC_8	,	KC_9	,	KC_0	,	S(KC_9)	,	S(KC_0)	,
			_______	,	KC_EXLM	,	KC_AT	,	KC_HASH	,	KC_DLR	,	KC_PERC	,							XXXXXXX	,	XXXXXXX	,	XXXXXXX	,	_______	,	KC_EQL	,	KC_QUOT	,	KC_BSLS	,
			_______	,	KC_CIRC	,	KC_AMPR	,	KC_ASTR	,	KC_LPRN	,	KC_RPRN	,	_______	,			_______	,	XXXXXXX	,	XXXXXXX	,	_______	,	_______	,	_______	,	_______	,
	KC_SPC	,							C(LWIN(KC_LEFT))	,	C(LWIN(KC_RIGHT))	,	_______	,	_______	,	_______	,	_______	,	_______	,	_______	,	_______
),
[_FN]=LAYOUT(    //FN (additional keys)
			_______	,	KC_F1	,	KC_F2	,	KC_F3	,	KC_F4	,	KC_F5	,							XXXXXXX	,	KC_PGDN	,	KC_UP	,	KC_PGUP	,	XXXXXXX	,	C(LWIN(KC_LEFT))	,	C(LWIN(KC_RIGHT))	,
			KC_CAPS	,	KC_F6	,	KC_F7	,	KC_F8	,	KC_F9	,	KC_F10	,							XXXXXXX	,	KC_LEFT	,	KC_DOWN	,	KC_RIGHT	,	XXXXXXX	,	XXXXXXX	,	XXXXXXX	,
			_______	,	XXXXXXX	,	XXXXXXX	,	XXXXXXX	,	XXXXXXX	,	XXXXXXX	,	_______	,			TO(_NUM)	,	XXXXXXX	,	KC_HOME	,	KC_DOWN	,	KC_END	,	XXXXXXX	,	XXXXXXX	,
	KC_SPC	,							_______	,	_______	,	_______	,	_______	,	_______	,	_______	,	_______	,	_______	,	_______
),
[_SYS]=LAYOUT(  //SYS (System utilz)
			RESET	,	RGB_TOG	,	RGB_VAD	,	RGB_VAI	,	KC_ASON	,	KC_ASOFF	,							XXXXXXX	,	XXXXXXX	,	XXXXXXX	,	XXXXXXX	,	XXXXXXX	,	XXXXXXX	,	XXXXXXX	,
			EEP_RST	,	RGB_MOD	,	RGB_SAD	,	RGB_SAI	,	KC_ASUP	,	KC_ASDN	,							XXXXXXX	,	XXXXXXX	,	XXXXXXX	,	XXXXXXX	,	XXXXXXX	,	XXXXXXX	,	XXXXXXX	,
			XXXXXXX	,	RGB_RMOD	,	RGB_HUD	,	RGB_HUI	,	KC_ASRP	,	XXXXXXX	,	XXXXXXX	,			XXXXXXX	,	XXXXXXX	,	XXXXXXX	,	XXXXXXX	,	XXXXXXX	,	XXXXXXX	,	XXXXXXX	,
	_______	,							_______	,	_______	,	_______	,	_______	,	XXXXXXX	,	_______	,	_______	,	_______	,	_______
)

};
int encoder_mode = 0;

bool process_record_user(uint16_t keycode, keyrecord_t *record) {
    switch (keycode) {
        case SW_ENCODER:
            if (record->event.pressed) {
                if (encoder_mode == 0) {
                    encoder_mode = 1;
                } else {
                    encoder_mode = 0;
                }
            }
            return false;
    }
    return true;
}

void keyboard_post_init_user(void) {
    //   rgblight_mode(RGBLIGHT_MODE_RGB_TEST);
#ifdef CONSOLE_ENABLE
    debug_enable = true;
    debug_matrix = true;
#endif
}


void encoder_update_user(uint8_t index, bool clockwise) {
    if (encoder_mode == 0) {
        register_code16(KC_LCTL);
        wait_ms(10);
        if (clockwise) {
            tap_code16(KC_MS_WH_DOWN);
        } else {
            tap_code16(KC_MS_WH_UP);
        }
        unregister_code16(KC_LCTL);

    } else {
        register_code16(KC_LALT);
        wait_ms(10);
        if (clockwise) {
            tap_code16(KC_MS_WH_DOWN);
        } else {
            tap_code16(KC_MS_WH_UP);
        }
        unregister_code16(KC_LALT);
    }
}
void encoder_update_kb(uint8_t index, bool clockwise) {
    encoder_update_user(index, clockwise);
}

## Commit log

2021-04-16 add qmk_firmware, pcb, via
    [WillowPecoe_plate_bottom.kicad_pcb, WillowPecoe_plate_bottom.sch, WillowPecoe_plate_top.kicad_pcb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]
2021-04-16 add pcb/kicad_lib
2021-04-16 fix kicad library path
    [willowPecoe.sch]

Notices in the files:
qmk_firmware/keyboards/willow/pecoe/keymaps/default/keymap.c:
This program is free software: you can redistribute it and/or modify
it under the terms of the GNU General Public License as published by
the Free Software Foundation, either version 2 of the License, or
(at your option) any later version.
